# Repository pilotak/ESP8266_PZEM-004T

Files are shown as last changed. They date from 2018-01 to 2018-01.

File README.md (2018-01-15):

# ESP_PZEM
## UNDER TESTING, FW under development
Board based on ESP8266-01 provides serial between with single or multiple PZEM-004T (with multiplexing). Built-in auto reset feature when uploading (GPIO0 is LOW). Fits above/under PZEM-004T board.

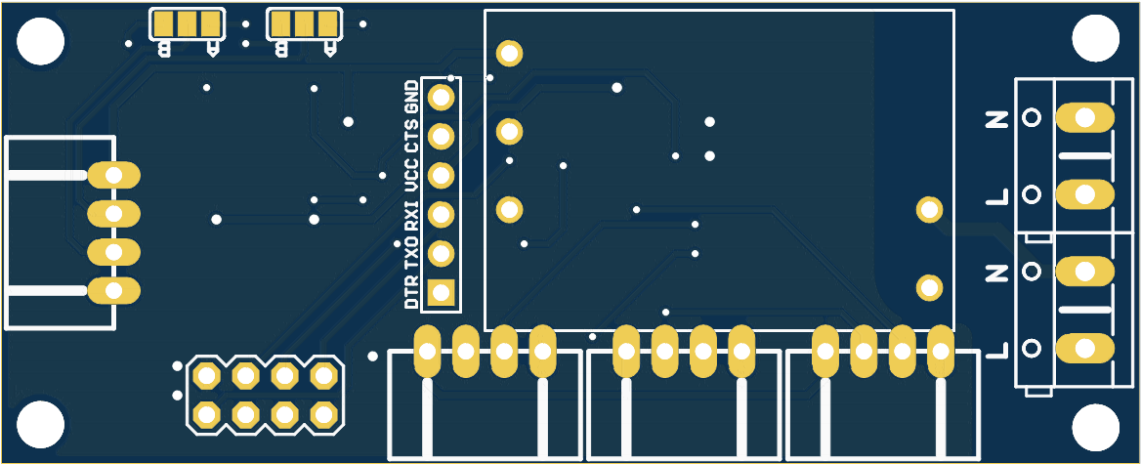
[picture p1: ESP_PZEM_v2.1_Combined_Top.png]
top


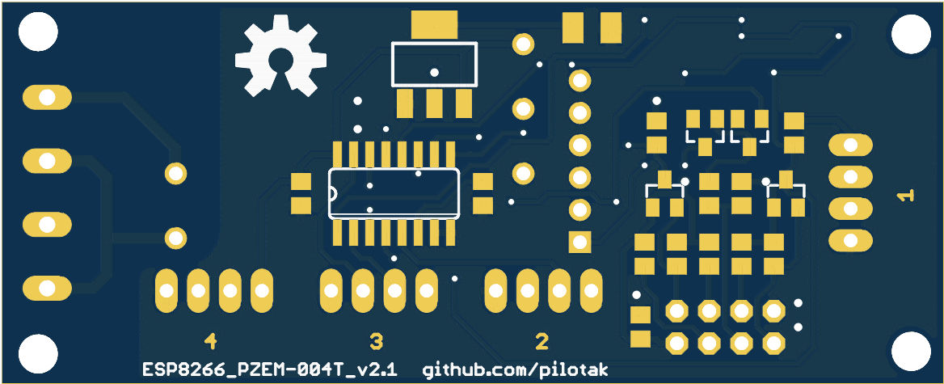
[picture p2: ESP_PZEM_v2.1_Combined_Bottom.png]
bottom


## BOM
### Single PZEM
Solder both jumpers to B

Qty | Value |Package
---|:---|:---
2 | 100n | 0805
1 | 100uF/6.3V | SMC_B
2 | BAT54C | SOT-23
1 | ESP01S | ESP-01
1 | FTDI_CONN | PINHEAD-6 
2 | BSS138 | SOT23
8 | 10K | 0805
1 | AC-DC-3.5W | AC-DC-3.5W
1 | LM1117-3.3 | SOT223
2 | KF301-5.0-2P | KF301-5.0-2P
1 | S4B-XH-A-1 | JST-XH-04-RIGHT-ANGLE

### Up to 4 PZEMs
Solder both jumpers to A

add to above

Qty | Value |Package
---|:---|:---
1 | 100n | 0805
1 | 74HC4052D | SO16
1 | 10K | 0805
3 | S4B-XH-A-1 | JST-XH-04-RIGHT-ANGLE

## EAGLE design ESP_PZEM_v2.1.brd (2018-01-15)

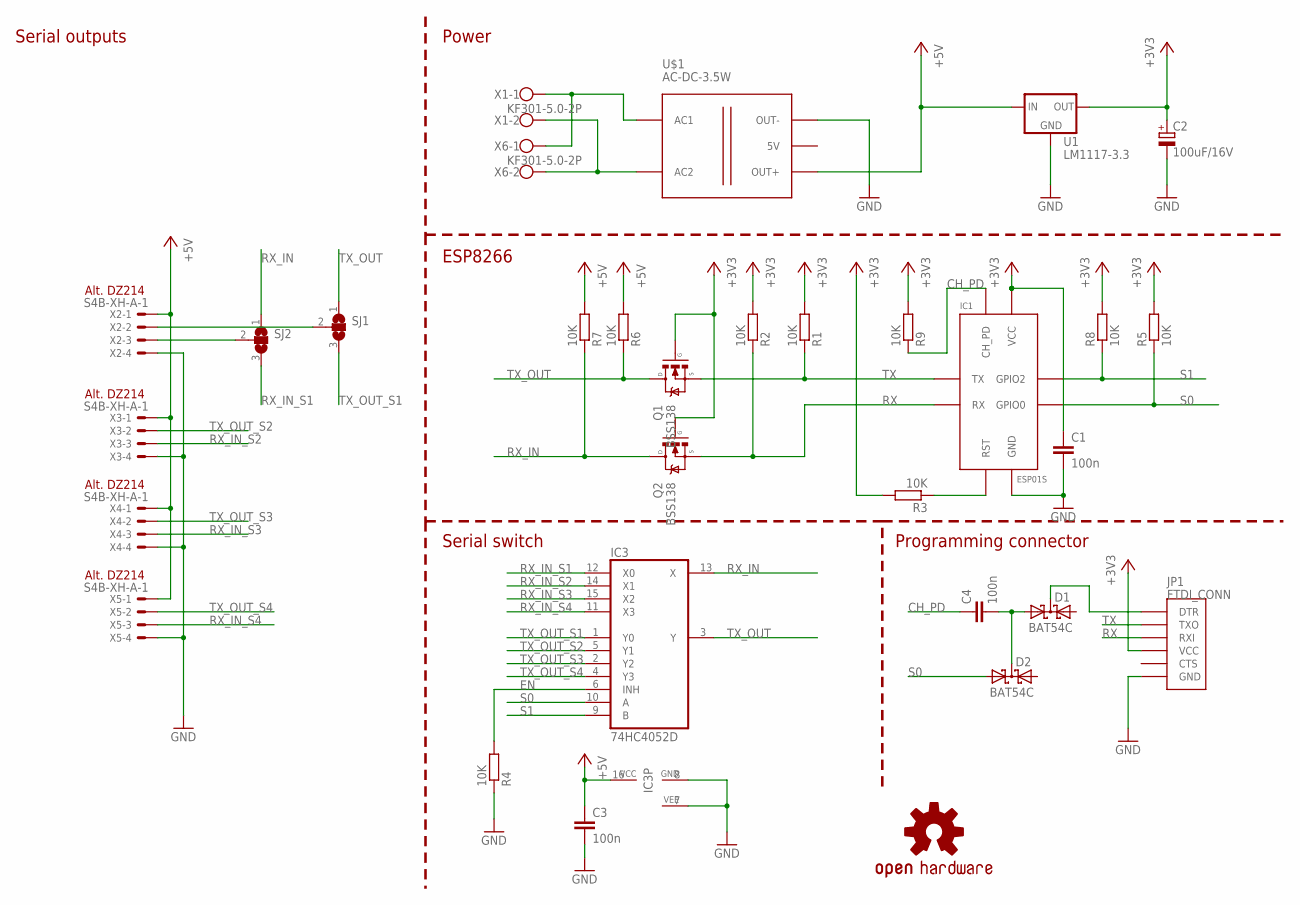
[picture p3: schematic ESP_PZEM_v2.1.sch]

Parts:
C1, C3, C4: 100n; C0805
C2: 100uF/16V; SMC_B
D1, D2: BAT54C; SOT23
IC1: ESP01S; ESP-01
IC3: 74HC4052D; SO16
JP1: FTDI_CONN; FTDI
LOGO1: OSHW-LOGOL; OSHW-LOGO-L
Q1, Q2: BSS138; SOT23
R1, R2, R3, R4, R5, R6, R7, R8, R9: 10K; R0805
SJ1, SJ2: SJ2W; SJ_2
U1: LM1117-3.3; SOT223
U$1: AC-DC-3.5W
X1, X6: KF301-5.0-2P
X2, X3, X4, X5: S4B-XH-A-1; JST-XH-04-PACKAGE-RIGHT

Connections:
+3V3: C1.1, C2.+, IC1.VCC, JP1.P$4 (VCC), Q1.1 (G), Q2.1 (G), R1.2, R2.2, R3.2, R5.2, R8.2, R9.2, U1.2 (OUT), U1.4 (OUT)
+5V: C3.1, IC3.16 (VCC), R6.2, R7.2, U1.3 (IN), U$1.J2.3 (OUT+), X2.1, X3.1, X4.1, X5.1
CH_PD: C4.1, IC1.CH_PD, R9.1
EN: IC3.6 (INH), R4.2
GND: C1.2, C2.-, C3.2, IC1.GND, IC3.7 (VEE), IC3.8 (GND), JP1.P$6 (GND), R4.1, U1.1 (GND), U$1.J2.1 (OUT-), X2.4, X3.4, X4.4, X5.4
L: U$1.J1.1 (AC1), X1.1, X6.1
N: U$1.J1.2 (AC2), X1.2, X6.2
unnamed: IC1.RST, R3.1
unnamed: C4.2, D1.1 (A1), D2.3 (CC)
unnamed: SJ1.2, X2.2
unnamed: SJ2.2, X2.3
unnamed: D1.3 (CC), JP1.P$1 (DTR)
RX: IC1.RX, JP1.P$3 (RXI), Q2.2 (S), R2.1
RX_IN: IC3.13 (X), Q2.3 (D), R7.1, SJ2.1
RX_IN_S1: IC3.12 (X0), SJ2.3
RX_IN_S2: IC3.14 (X1), X3.3
RX_IN_S3: IC3.15 (X2), X4.3
RX_IN_S4: IC3.11 (X3), X5.3
S0: D2.1 (A1), IC1.GPIO0, IC3.10 (A), R5.1
S1: IC1.GPIO2, IC3.9 (B), R8.1
TX: IC1.TX, JP1.P$2 (TXO), Q1.2 (S), R1.1
TX_OUT: IC3.3 (Y), Q1.3 (D), R6.1, SJ1.1
TX_OUT_S1: IC3.1 (Y0), SJ1.3
TX_OUT_S2: IC3.5 (Y1), X3.2
TX_OUT_S3: IC3.2 (Y2), X4.2
TX_OUT_S4: IC3.4 (Y3), X5.2

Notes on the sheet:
ESP8266
Power
Serial outputs
Serial switch
Programming connector
Alt. DZ214

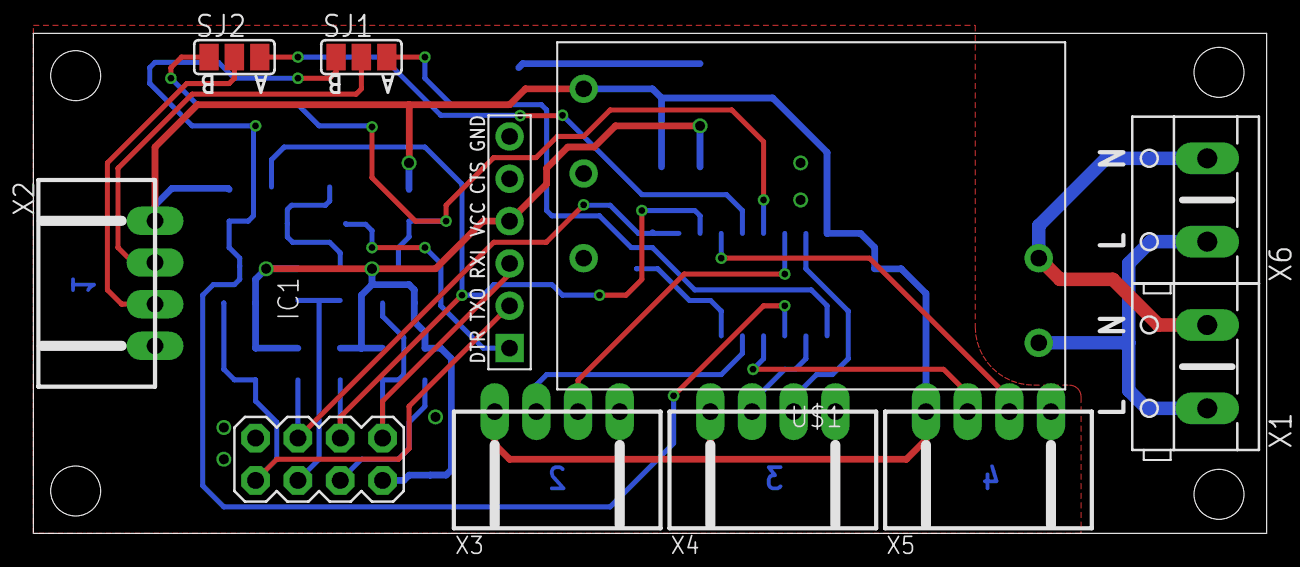
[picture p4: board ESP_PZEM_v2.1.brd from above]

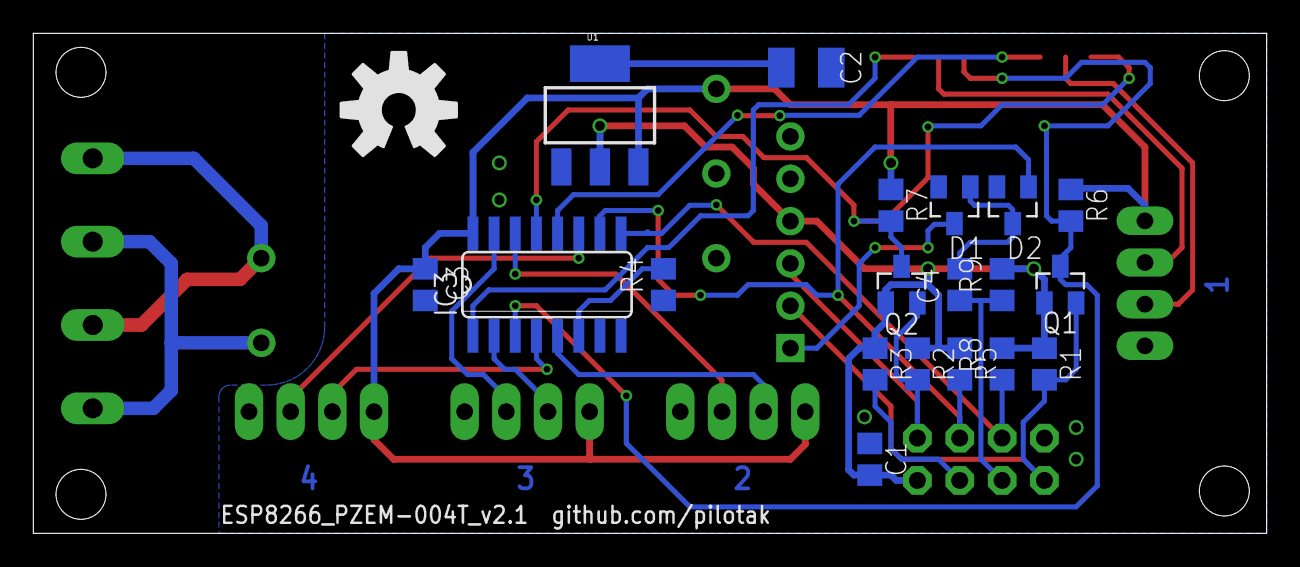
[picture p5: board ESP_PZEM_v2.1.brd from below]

Board: 2 copper layers, 74.0 x 30.0 mm, 31 parts (20 on the bottom side), 26 nets.

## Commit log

2018-01-14 SS16 -> BAT54C
    [ESP_PZEM_v2.1.brd, ESP_PZEM_v2.1.sch]
2018-01-15 resistor moved
    [ESP_PZEM_v2.1.brd]

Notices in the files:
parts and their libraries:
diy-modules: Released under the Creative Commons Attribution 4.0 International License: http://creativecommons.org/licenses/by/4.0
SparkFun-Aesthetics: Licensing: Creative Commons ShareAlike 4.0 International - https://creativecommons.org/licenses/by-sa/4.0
